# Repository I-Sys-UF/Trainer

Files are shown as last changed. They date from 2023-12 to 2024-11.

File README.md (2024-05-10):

# I.Sys Programming Trainer の使い方

## KiCAD プロジェクト

`./ISysProgrammingTrainerTypeA/` 以下に配置

### 回路図

<div align="center">
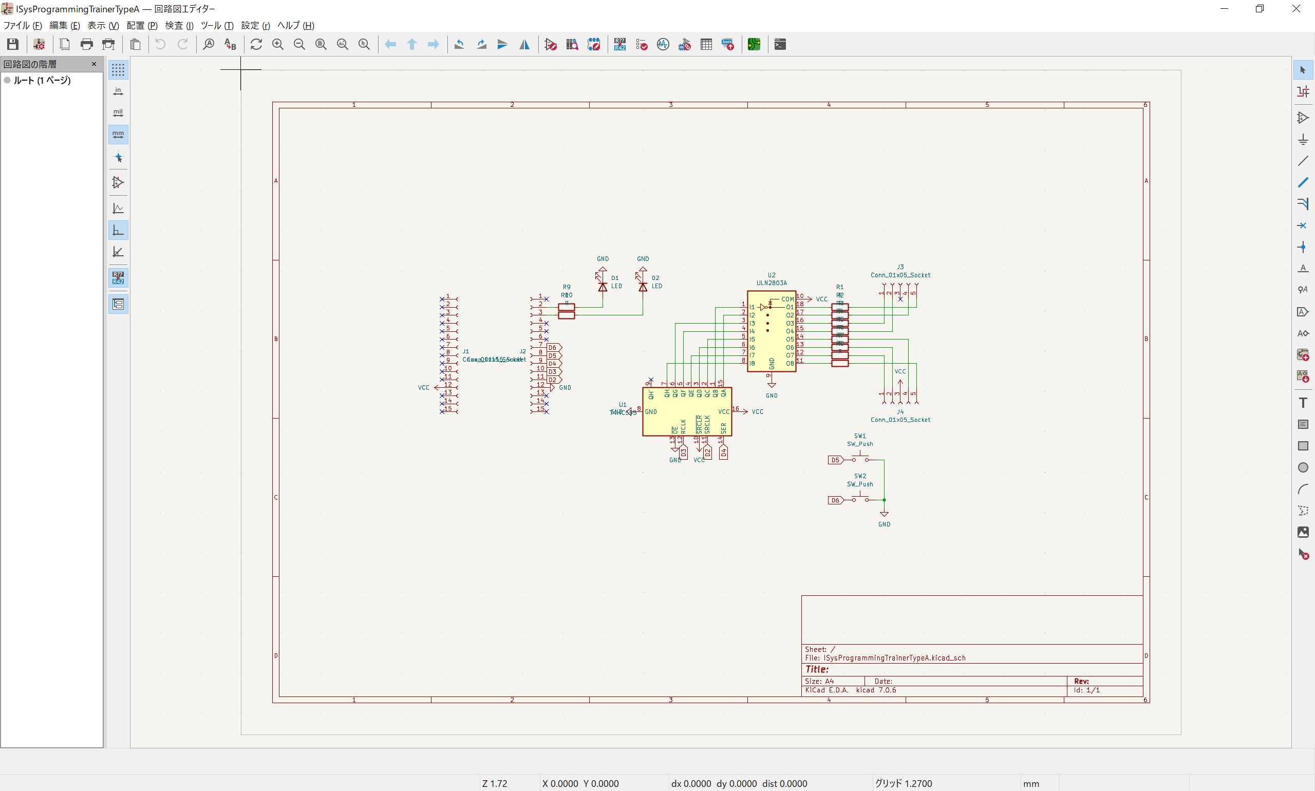
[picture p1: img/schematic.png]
  
</div>

### 基板デザイン

<div align="center">
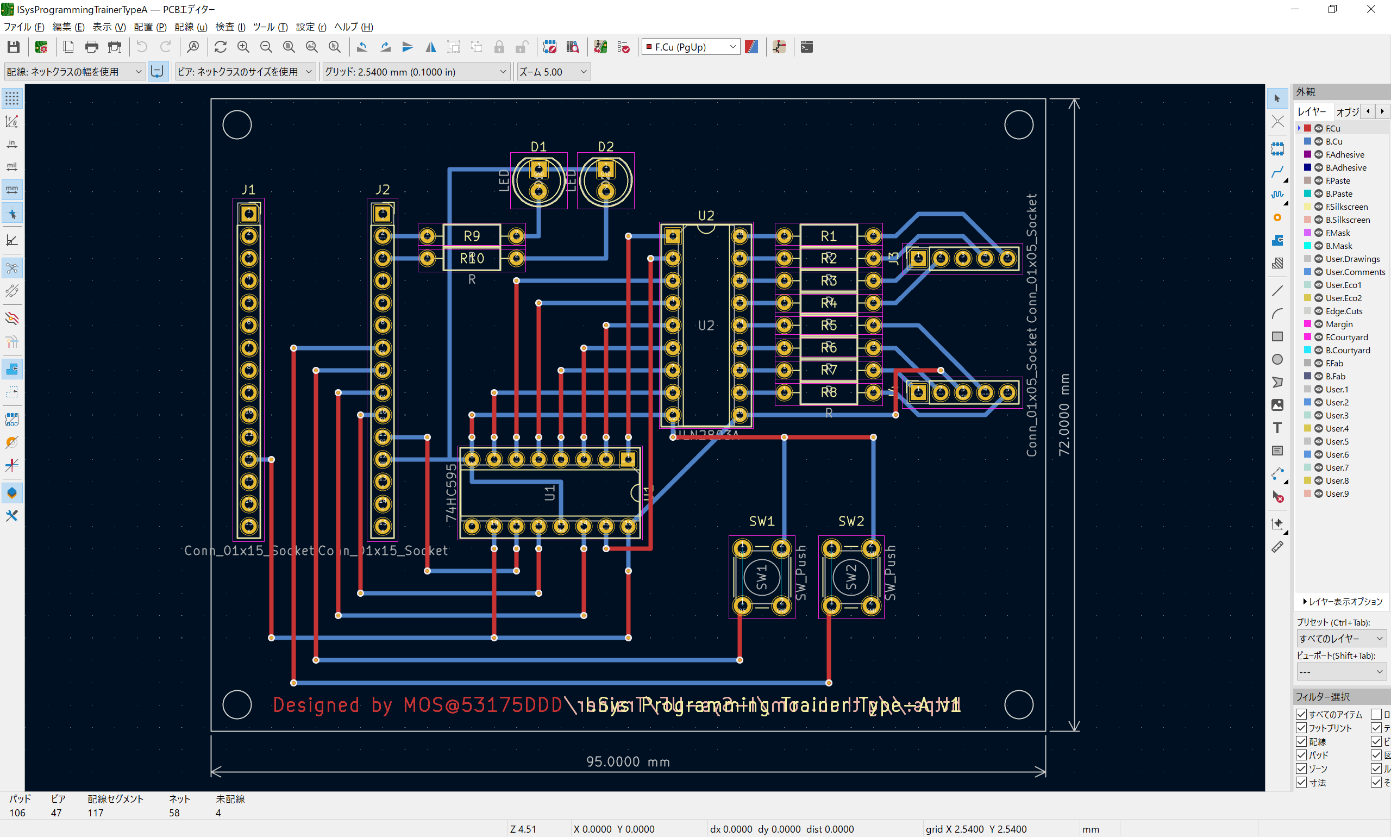
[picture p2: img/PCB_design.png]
  
</div>

### 3D プレビュー

<div align="center">
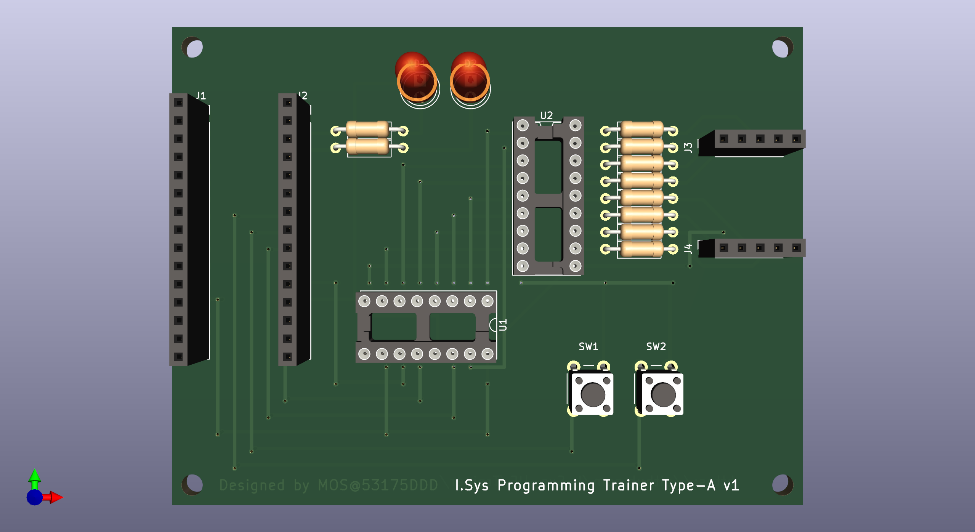
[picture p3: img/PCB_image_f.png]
  
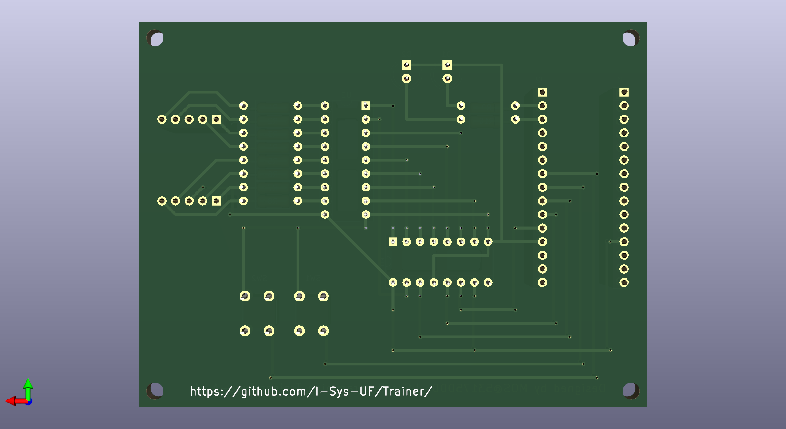
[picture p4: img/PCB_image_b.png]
  
</div>

## 進め方

<https://i-sys-uf.github.io/docs/edu/getting_started_programming> を読みながら進めてください

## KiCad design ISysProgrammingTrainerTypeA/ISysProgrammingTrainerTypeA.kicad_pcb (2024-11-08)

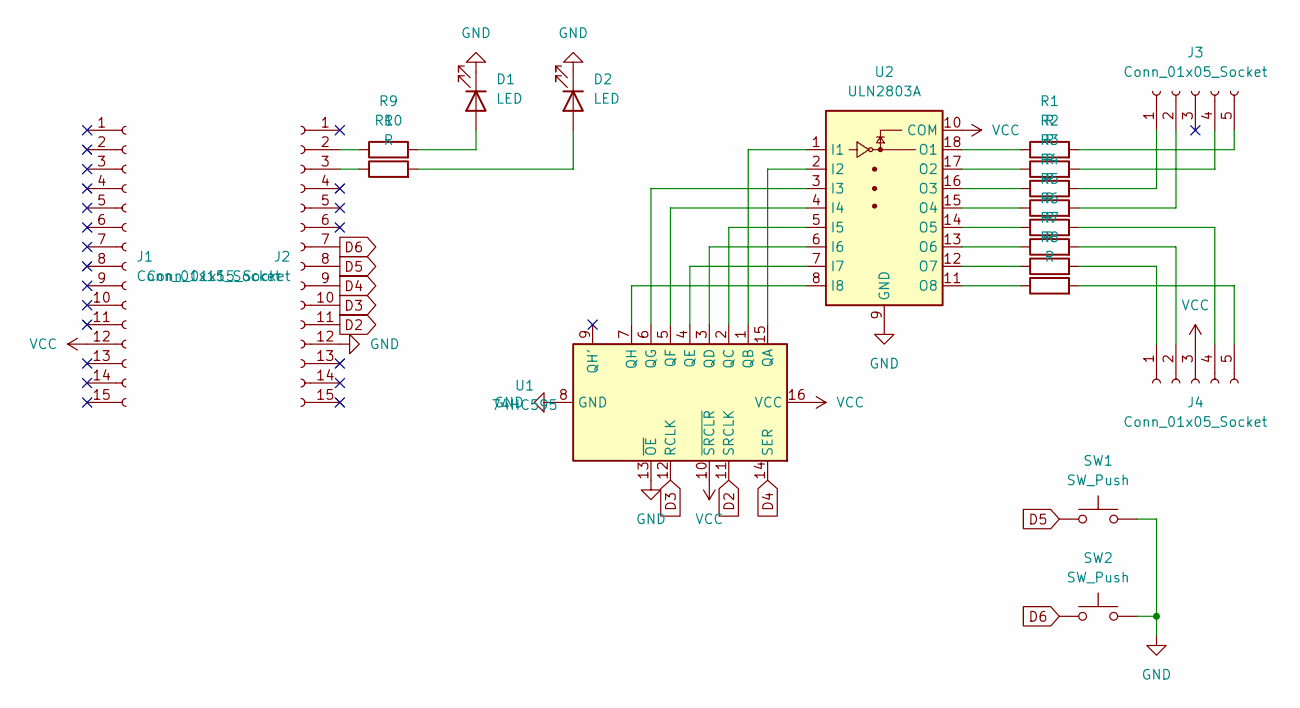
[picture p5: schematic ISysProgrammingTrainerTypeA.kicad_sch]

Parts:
D1, D2: LED; LED_D5.0mm
J1, J2: Conn_01x15_Socket; PinSocket_1x15_P2.54mm_Vertical
J3, J4: Conn_01x05_Socket; PinSocket_1x05_P2.54mm_Vertical
R1, R2, R3, R4, R5, R6, R7, R8, R9, R10: R; R_Axial_DIN0207_L6.3mm_D2.5mm_P10.16mm_Horizontal
SW1, SW2: SW_Push; SW_PUSH_6mm
U1: 74HC595; DIP-16_W7.62mm_Socket
U2: ULN2803A; DIP-18_W7.62mm_Socket

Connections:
D2: J2.11, U1.11 (SRCLK)
D3: J2.10, U1.12 (RCLK)
D4: J2.9, U1.14 (SER)
D5: J2.8, SW1.1
D6: J2.7, SW2.1
GND: D1.1 (K), D2.1 (K), J2.12, SW1.2, SW2.2, U1.8 (GND), U1.13 (~OE), U2.9 (GND)
unnamed: D1.2 (A), R9.2
unnamed: D2.2 (A), R10.2
unnamed: J2.2, R9.1
unnamed: J2.3, R10.1
unnamed: J3.1, R3.2
unnamed: J3.2, R4.2
unnamed: J3.4, R2.2
unnamed: J3.5, R1.2
unnamed: J4.1, R7.2
unnamed: J4.2, R6.2
unnamed: J4.4, R5.2
unnamed: J4.5, R8.2
unnamed: U1.15 (QA), U2.2 (I2)
unnamed: U1.1 (QB), U2.1 (I1)
unnamed: U1.2 (QC), U2.5 (I5)
unnamed: U1.3 (QD), U2.6 (I6)
unnamed: U1.4 (QE), U2.7 (I7)
unnamed: U1.5 (QF), U2.4 (I4)
unnamed: U1.6 (QG), U2.3 (I3)
unnamed: U1.7 (QH), U2.8 (I8)
unnamed: R1.1, U2.18 (O1)
unnamed: R2.1, U2.17 (O2)
unnamed: R3.1, U2.16 (O3)
unnamed: R4.1, U2.15 (O4)
unnamed: R5.1, U2.14 (O5)
unnamed: R6.1, U2.13 (O6)
unnamed: R7.1, U2.12 (O7)
unnamed: R8.1, U2.11 (O8)
VCC: J1.12, J4.3, U1.10 (~SRCLR), U1.16 (VCC), U2.10 (COM)

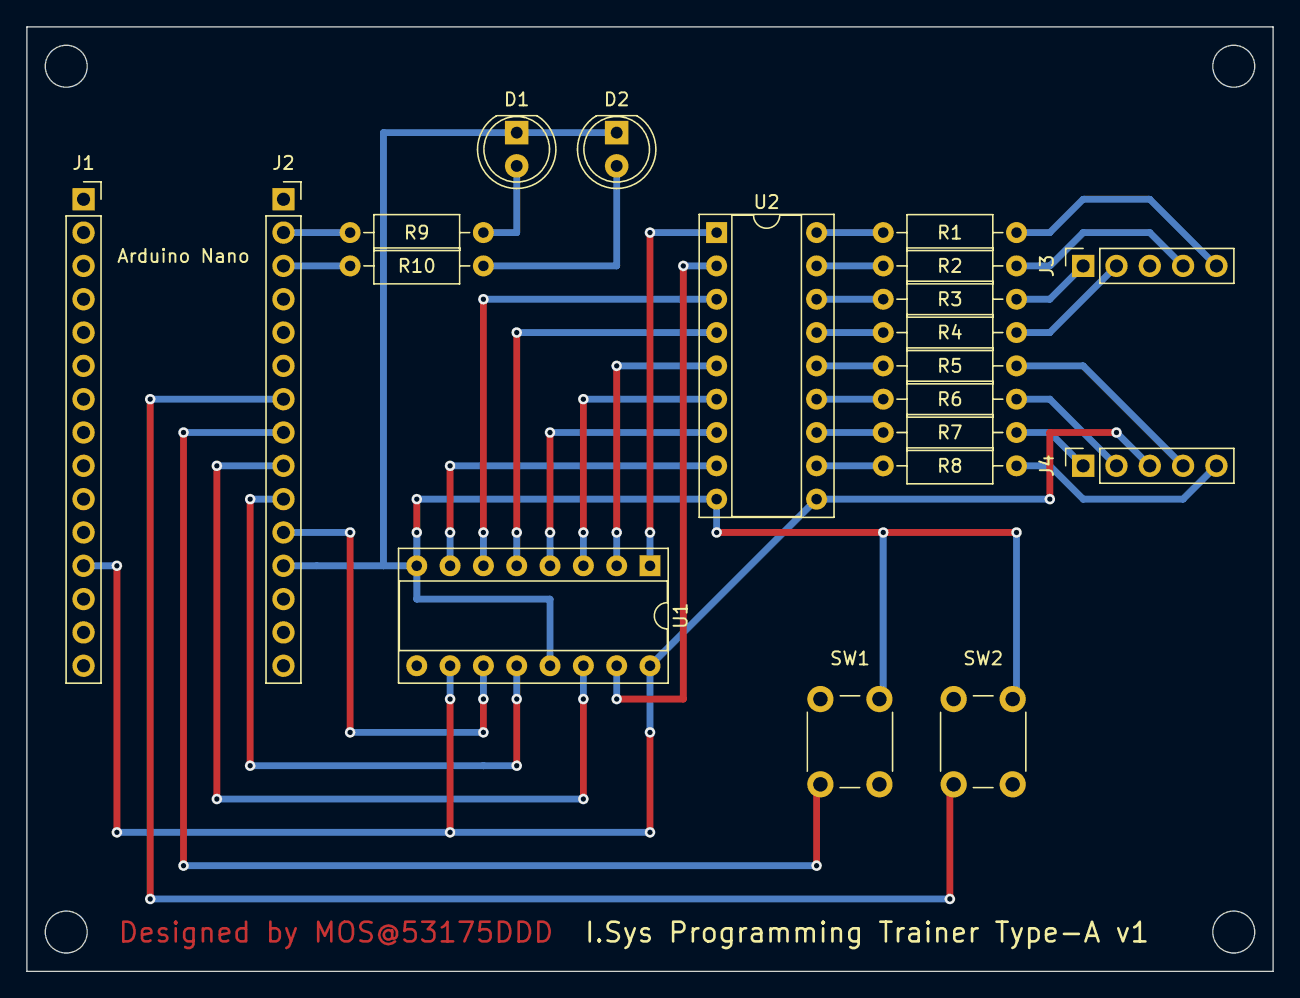
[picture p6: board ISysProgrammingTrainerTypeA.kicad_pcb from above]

Board: 2 copper layers, 95.0 x 72.0 mm, 20 parts (0 on the bottom side), 35 nets.

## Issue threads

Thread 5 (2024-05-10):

百田篤志

53175ddd, 2024-05-10:
【はじめに】

- [ ] 基板の組み立て
  はんだ付けは基本的に背の低い部品から行う
  - [ ] 抵抗をはんだ付け
  - [ ] IC ソケットをはんだ付け
  - [ ] スイッチをはんだ付け
  - [ ] LED をはんだ付け
    向きに注意
  - [ ] ピンソケットをはんだ付け
  - [ ] Arduino Nano にピンヘッダをはんだ付け
  - [ ] IC をソケットに挿入
  - [ ] Arduino Nano を挿入
  - [ ] 7 セグメント LED を挿入
  - [ ] スペーサを付ける

 【準備】

- [ ] GitHub リポジトリを丸ごとダウンロードする
  「<> Code」 -> 「Download ZIP」
- [ ] ダウンロードした ZIP ファイルを `D:Arduino/` あたりに展開する

【プログラミングの学習】

資料はブラウザで見るとよい．リポジトリトップの README にリンクがあるのでそこから飛べる

- [ ] `TrainingKit-demo` を資料を見ながら進める
- [ ] `Train-1` を資料を見ながら進める
  - [ ] 理解できた？
- [ ] `Train-2` を資料を見ながら進める
  - [ ] 理解できた？
- [ ] `Train-3` を資料を見ながら進める
  - [ ] 理解できた？
- [ ] `Train-4` を資料を見ながら進める
  - [ ] 理解できた？
- [ ] `Train-5` を資料を見ながら進める
  - [ ] 理解できた？
- [ ] `Train-6` を資料を見ながら進める
  - [ ] 理解できた？
- [ ] `Train-7` を資料を見ながら進める
  - [ ] 理解できた？
- [ ] `Train-8` を資料を見ながら進める
  - [ ] 理解できた？

【プログラミングの実践】

- [ ] オリジナルのプログラムを最低 1 つ作成する

わからないところは随時質問しよう

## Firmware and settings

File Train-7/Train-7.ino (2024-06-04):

/* スイッチと，繋がっている GPIO の対応を定義 */
#define SW1 5
#define SW2 6

/* LED と，繋がっている GPIO の対応を定義*/
#define LED_D1 11
#define LED_D2 10

/* スイッチの状態ごと GPIO の状態を定義しておく */
#define SW_isPressed   LOW
#define SW_isReleased HIGH

/* ピンアサインの定義 */
#define ShiftRegister_IN  4
#define ShiftRegister_CLK 2
#define ShiftRegister_SET 3

/* 数字をバイナリに変換する配列 */
uint8_t num_to_bin[] = {0b11111100, 0b01100000, 0b11011010, 0b11110010,   // 0, 1, 2, 3
                        0b01100110, 0b10110110, 0b10111110, 0b11100100,   // 4, 5, 6, 7
                        0b11111110, 0b11110110, 0b11101110, 0b00111110,   // 8, 9, A, b
                        0b00011010, 0b01111011, 0b10011110, 0b10001110};  // c, d, E, F

void setup() {
  /* LED が繋がっている GPIO を出力に設定する */
  pinMode(LED_D1, OUTPUT);
  pinMode(LED_D2, OUTPUT);

  /* スイッチが繋がっている GPIO を入力に設定し，内部プルアップ抵抗を有効にする */
  pinMode(SW1,  INPUT_PULLUP);
  pinMode(SW2,  INPUT_PULLUP);

  /* 74HC595 で使用する GPIO を初期化 */
  pinMode(ShiftRegister_IN , OUTPUT);  digitalWrite(ShiftRegister_IN ,  LOW);
  pinMode(ShiftRegister_CLK, OUTPUT);  digitalWrite(ShiftRegister_CLK,  LOW);
  pinMode(ShiftRegister_SET, OUTPUT);  digitalWrite(ShiftRegister_SET,  LOW); 
}

void loop() {
  /* スイッチの状態を保存する変数を用意する */
  /* 頭の static については正常に動作させるために必要なものと思っておこう */
  static uint8_t SW1_Status_New, SW2_Status_New;
         uint8_t SW1_Status_Old, SW2_Status_Old;

  /* カウンター変数を用意する．頭の static については以下同文 */
  static int8_t counter = 0;

  /* スイッチの状態の変数を更新する */
  SW1_Status_Old = SW1_Status_New;
  SW2_Status_Old = SW2_Status_New;
  SW1_Status_New = digitalRead(SW1);
  SW2_Status_New = digitalRead(SW2);

  /* "押された瞬間" はつまり 一つ前は押されてなくて今は押されているということになる */
  if((SW2_Status_Old == SW_isReleased) && (SW2_Status_New == SW_isPressed)) {
    counter++;  // これで 1 加算される（インクリメント演算子）
    digitalWrite(LED_D2, HIGH);  // 押された瞬間に LED を光らせる
  }else {
    digitalWrite(LED_D2,  LOW);  // LED を消す
  }

  if((SW1_Status_Old == SW_isReleased) && (SW1_Status_New == SW_isPressed)) {
    counter--;  // これで 1 減算される（デクリメント演算子）
    digitalWrite(LED_D1, HIGH);  // 押された瞬間に LED を光らせる
  }else {
    digitalWrite(LED_D1,  LOW);  // LED を消す
  }

  /* オーバーフローを防止する */
  if(counter < 0) {
    counter = 0;
  }
  
  if(counter > 15) {
    counter = 15;
  }

  /* 7 セグに表示する */
  LED_OUT(num_to_bin[(uint8_t)counter]);

  /* 少し待つ */
  delay(25);
}

void LED_OUT(uint8_t data) {
  /* 独自実装の shiftOut 関数 */
  for(uint8_t i = 0; i < 8; i++) {
    digitalWrite(ShiftRegister_IN , (data & 1 << i) == 0 ? 0 : 1);
    digitalWrite(ShiftRegister_CLK, HIGH);
    digitalWrite(ShiftRegister_CLK,  LOW);
  }
  digitalWrite(ShiftRegister_SET, HIGH);
  digitalWrite(ShiftRegister_SET,  LOW);
}

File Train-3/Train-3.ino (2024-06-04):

/* 今度は関数を作ってみる */

void setup() {
  /* 計算結果を見れるようにシリアル通信を使いたいので，これを実行してシリアル通信を有効にする */
  /* Ctrl + Shift + M でシリアルモニタを開いておこう */
  Serial.begin(9600);
  delay(250);

  /* 適当な定数 x を代入する．実行するごとに変えてみよう */
  float x = 2.5;

  /* 関数に値を渡して呼び出し，計算を実行する */
  float y = f(x);

  /* ここでの x と f() の関数の中での x, y は結果として同じ値になるが，CPU から見れば全くの別物 */
  /* つまり， float a = 1.5; float n = f(a); などとしても問題ない */

  /* 計算結果をシリアルモニタに表示する */
  Serial.print("f(");
  Serial.print(x);
  Serial.print(") = ");
  Serial.print(y);
  Serial.print("\n");
}  

void loop() {
}

/* 何かしらの x の式を実装してみる */
/* ここでは f(x) = 4x^2 + 6x - 10 を実装する */
float f(float x) {
  /* 計算結果を代入する変数を用意 */
  float y;

  /* 計算する */
  y = 4 * x * x + 6 * x - 10;

  /* 計算結果を戻す */
  return y;
}

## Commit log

2023-12-07 タイマー割り込みを使うように変更
2023-12-07 define 文を追加
2023-12-07 目次作成
2023-12-07 目次追加
2023-12-07 基板データ作成
    [ISysProgrammingTrainerTypeA.kicad_pcb, ISysProgrammingTrainerTypeA.kicad_sch]
2023-12-07 シルク印刷にリポジトリのリンクを追加
    [ISysProgrammingTrainerTypeA.kicad_pcb]
2023-12-07 Train を追加
2023-12-08 LED_VRAM に突っ込む値を変更
2023-12-08 トレーニングプログラムを追加
2023-12-08 押された瞬間にだけ LED が光るように変更
2023-12-09 bug fix
    - LED_OUT が存在しない問題を修正
    - `sprintf` が float を表示できない問題を修正
    [Train-3.ino, Train-5.ino, Train-8.ino]
2023-12-13 回路図の配置を変更
    [ISysProgrammingTrainerTypeA.kicad_sch]
2023-12-13 README 更新．画像を追加
2024-05-01 ドキュメント追加
2024-05-01 誤字修正
2024-11-08 シルク印刷を追加
    `Arduino Nano` の刻印を追加
    [ISysProgrammingTrainerTypeA.kicad_pcb]
